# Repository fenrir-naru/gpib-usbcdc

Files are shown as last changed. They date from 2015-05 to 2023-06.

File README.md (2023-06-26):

GPIB-USBCDC
===============

_GPIB-USBCDC_ is an interface bridge between GPIB (HPIB) and USB communication device class. 
It is [Prologix GPIB-USB adapter](http://prologix.biz/gpib-usb-controller.html) clone with [EFM8 Universal Bee](https://www.silabs.com/products/mcu/8-bit/efm8-universal-bee/pages/efm8-universal-bee.aspx) or [C8051F38x](http://www.silabs.com/products/mcu/8-bit/c8051f38x/Pages/c8051f38x.aspx) microcontroller.

# Quick user guide
  1. Connect _GPIB-USBCDC_ to the PC. _GPIB-USBCDC_ is recognized as serial port, which will be installed with [CDC inf file](https://raw.githubusercontent.com/fenrir-naru/gpib-usbcdc/master/firmware/inf/gpib-usbcdc_C8051F38x.inf).
  1. Other usage is almost same as [Prologix GPIB-USB adapter](http://prologix.biz/gpib-usb-controller.html). Please see that product manual.
  
# Manual
[Nice user manual](https://github.com/fenrir-naru/gpib-usbcdc/blob/master/docs/manual_by_Alessandro.pdf) written by Alessandro Soraruf is available, Thanks!
In addition, please set up your device with its address except for zero, in case of bus confliction reported by [biergaizi](https://github.com/fenrir-naru/gpib-usbcdc/issues/5).
  
# Board
[EagleCAD](http://www.cadsoftusa.com/) files are available (ver.1 [schematics](https://github.com/fenrir-naru/gpib-usbcdc/blob/master/board/gpib-usbcdc.sch) and [layout](https://github.com/fenrir-naru/gpib-usbcdc/blob/master/board/gpib-usbcdc.brd). Its components are listed in [BOM](https://github.com/fenrir-naru/gpib-usbcdc#bom-bill-of-material). The board design is published under [Creative Commons Attribution-ShareAlike 4.0 International](http://creativecommons.org/licenses/by-sa/4.0/).

## BOM (bill of material)

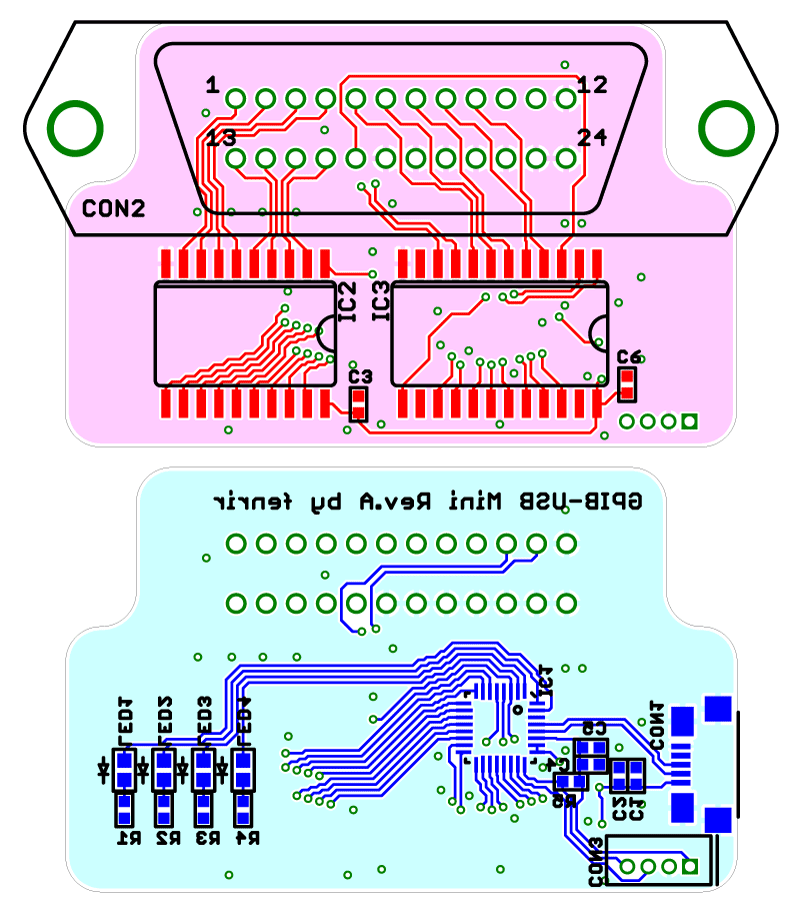
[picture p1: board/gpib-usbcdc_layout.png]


| **Part** | **Value** | **Package** | **Multiple** |
|:---|:---|:---|:---|
| C1, C4  | 1u / 6V3 | 1005 | 2 |
| C2, C3, C5, C6 | 0.1u / 10V | 1005 | 4 |
| CON1 | [HRS ZX62R-B-5P](http://www.digikey.jp/product-detail/ja/ZX62R-B-5P/H11574CT-ND/1787106) | | 1 |
| CON2 | [Norcomp 111-024-113L001](http://www.digikey.jp/product-detail/ja/0/1024PMA-ND) | | 1 |
| CON3 | [JST ZH B4B-ZR](http://www.jst-mfg.com/product/detail_e.php?series=287) | | 1 | 
| IC1 | [EFM8UB20F32G-A-QFN32](https://www.silabs.com/products/mcu/8-bit/efm8-universal-bee/pages/EFM8UB20F32G-A-QFN32.aspx) or [C8051F387-GM](http://www.silabs.com/products/mcu/8-bit/c8051f38x/pages/C8051F387-GM.aspx) | QFN32 | 1 |
| IC2 | [SN75160BDWR](http://www.ti.com/product/sn75160b) or [SN75ALS160DWR](http://www.ti.com/product/sn75als160) | SO20 | 1 |
| IC3 | [SN75162BDWR](http://www.ti.com/product/sn75162b) or [SN75ALS162DWR](http://www.ti.com/product/sn75als162) | SO24 | 1 |
| LED1 | Red | 1608 | 1 |
| LED2 | Orange | 1608 | 1 |
| LED3 | Green | 1608 | 1 |
| LED4 | Blue | 1608 | 1 |
| R1, R2, R3, R4 | 470 | 1005 | 4 |
| R5 | 1K | 1005 | 1 |

# Firmware
The official binary is published in [github release](https://github.com/fenrir-naru/gpib-usbcdc/releases). To build the firmware by yourself, install [sdcc](http://sdcc.sourceforge.net/) (testing with [ver 3.3.0 #8604](http://sourceforge.net/projects/sdcc/files/sdcc/3.3.0/)), and just "make" at "firmware" directory of the downloaded [code](https://github.com/fenrir-naru/gpib-usbcdc/tree/master/firmware). The generated firmware name is  `gpib-usbcdc.hex`. The firmware code is published under [New BSD License](http://opensource.org/licenses/BSD-3-Clause). 



## How to write firmware to hardware
Connect a _GPIB-USBCDC_ board and a PC via [USB debug adapter (UDA)](http://www.silabs.com/products/mcu/pages/usbdebug.aspx) or compatible one. The minimum required programming connections are summarized in the following table. Then, use [Flash Programming Utilities](http://www.silabs.com/products/mcu/Pages/8-bit-microcontroller-software.aspx#flash). Note: the board may not be recognized by a PC when an UDA is connected via USB hubs. UDA is recommended to connect a PC directly.

| **Signal** | **UDA side** | **_GPIB-USBCDC_ board side** |
|:---|:---|:---|
| C2D | 4th pin | CON3 3rd pin |
| C2CK | 7th pin | CON3 4th pin |
| GND | 3rd pin | CON3 1st pin |

# Additional information
* The project owner's website is [Fenrir's BLog](http://fenrir.naruoka.org/).

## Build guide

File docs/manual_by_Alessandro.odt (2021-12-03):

fenrir / hugen79

GPIB-USBCDC CONTROLLER

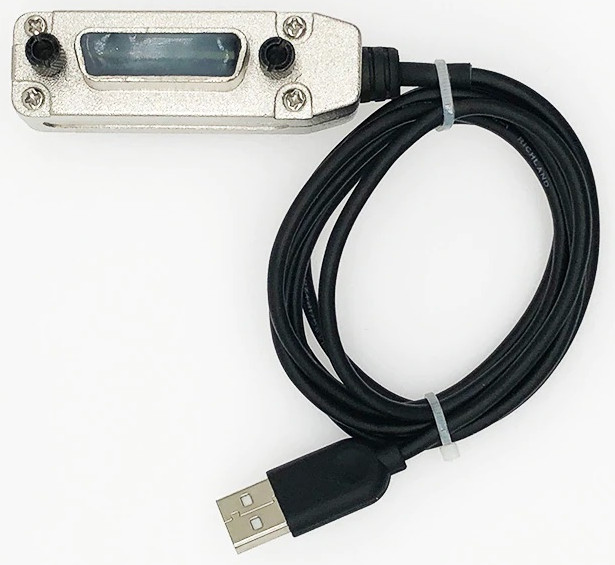
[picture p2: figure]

USER MANUAL

Version 1.2

Dec 02, 2021

Change Log

Nov 27, 2021 | Initial version
Nov 29, 2021 | Added “debug 0” description
Dec 02, 2021 | Added Hugen79 pics and FW update connector pin description

# Introduction

Fenrir GPIB-USBCDC is an interface bridge between GPIB (HPIB) and USB communication device class. It is a Prologix GPIB-USB adapter clone with EFM8 Universal Bee or C8051F38x microcontroller.

Fenrir GPIB-USBCDC controller converts any computer with a USB port into a GPIB Controller or Device.

In Controller mode, Fenrir GPIB-USBCDC controller can remotely control GPIB enabled instruments such as Oscilloscopes, Logic Analyzers, and Spectrum Analyzers.

In Device mode, Fenrir GPIB-USBCDC controller converts the computer into a GPIB peripheral for downloading data and screen plots from the instrument front panel.

In both modes, Fenrir GPIB-USBCDC controller interprets high level commands received from the host computer and performs the appropriate low-level GPIB protocol handshaking.

# Installation

Fenrir GPIB-USBCDC controller is recognized as serial port, which will be installed with CDC .inf file. To install it, simply connect the Fenrir GPIB-USBCDC to the PC and it will be automatically discovered and installed by the operating system.

# Firmware

The official firmware binary is published in github release (https://github.com/fenrir-naru/gpib-usbcdc/releases). To build the firmware by yourself, install Small Device C Compiler - S (http://sdcc.sourceforge.net/)DCC (testing with ver 3.3.0 #8604 (http://sourceforge.net/projects/sdcc/files/sdcc/3.3.0/)), and just "make" at "firmware" directory of the downloaded code. The generated firmware name is gpib-usbcdc.hex. The firmware code is published under New BSD License (http://opensource.org/licenses/BSD-3-Clause).

Depending on the hardware you are using you will need the original fenrir firmware or hugen79 modded firmware.

Fenrir git URL: https://github.com/fenrir-naru/gpib-usbcdc

Hugen79 git URL: https://github.com/hugen79/gpib-usbcdc

## Write firmware to hardware

Connect a GPIB-USBCDC board and a PC via USB debug adapter (UDA) (http://www.silabs.com/products/mcu/pages/usbdebug.aspx) or compatible one. The minimum required programming connections are summarized in the following table. Then, use Flash Programming Utilities (http://www.silabs.com/products/mcu/Pages/8-bit-microcontroller-software.aspx#flash).

Note:

the board may not be recognized by a PC when an UDA is connected via USB hubs. UDA is recommended to connect a PC directly.

Signal | UDA side | Fenrir GPIB-USBCDC board side | Hugen79 GPIB-USBCDC board side
C2D | 4th pin | CON3 3rd pin | V.D.C.G. 2nd pin
C2CK | 7th pin | CON3 4th pin | V.D.C.G. 3rd pin
GND | 3rd pin | CON3 1st pin | V.D.C.G. 4th pin

See Fenrir layout and Hugen79 PCB for more detail on connectors.

# Host Software

A wide variety of host software may be used to communicate with Fenrir GPIB-USBCDC controller:

Terminal programs – any terminal emulation program such as HyperTerminal, Tera Term Pro, or Minicom can be used to communicate with the controller and instruments connected to it.

Custom applications – any programming language or environment that provides access to serial ports (if using VCP driver) or allows interfacing to DLL (if using D2XX driver) may be used to develop custom applications. Graphical programming environments like National Instruments LabView and Agilent VEE may be used as well.

EZGPIB – an easy to use, programming environment developed by Ulrich Bangert for developing data acquisition applications. Web link to this tool can be found at prologix.biz.

Plotter emulators – plotter emulation applications such as 7470.exe, PrintCapture and Plottergeist can be used to render screen plots downloaded using Fenrir GPIB-USBCDC controller. Details on how to configure these tools are available at prologix.biz.

# Configuration

Fenrir GPIB-USBCDC controller can be configured using any of the following methods:

Prologix.exe – Prologix.exe is an open source tool developed by John Miles for configuring the controller. Web link to the tool can be found at prologix.biz.

Terminal program – any terminal emulation program such as HyperTerminal, Tera Term Pro, or Minicom can be used to configure the controller by manually entering appropriate commands (See Commands). Using the terminal program open the virtual COM port created by the USB driver. Serial port parameters such as baud rate, data bits, stop bits and flow control do not matter and may be set to any value. You may want to enable the “Local Echo” feature in the terminal program to view the commands being entered. Please consult the FAQ at prologix.biz, or the program’s user manual, for detailed configuration steps for various terminal programs.

Fenrir GPIB-USBCDC Controller stores the latest configuration settings in non-volatile memory. These settings are not address specific. If you have multiple instruments on the GPIB bus that require different configuration settings, you must change the settings before communicating with each instrument.

# Operating Modes

Fenrir GPIB-USBCDC controller can operate in two modes – CONTROLLER and DEVICE. You can switch between the two modes using ++mode command (see Commands).

## Controller Mode

In Controller mode, the GPIB-USB Controller acts as the Controller-In-Charge (CIC) on the GPIB bus. When the controller receives a command over the USB port terminated by the USB terminator – CR (ASCII 13) or LF (ASCII 10) – it addresses the GPIB instrument at the currently specified address (See ++addr command) to listen, and passes along the received data.

When Read-After-Write feature is enabled (See ++auto command) Fenrir GPIB-USBCDC Controller will addresses the instrument to talk after sending a command, in order to read its response. All data received from instruments over GPIB is sent to host over USB. Read-After-Write feature simplifies communication with instruments. You send commands and read responses without consideration for low level GPIB protocol details.

When Read-After-Write feature is not enabled Fenrir GPIB-USBCDC controller does not automatically address the instrument to talk. You must use the ++read command to read data.

Controller mode is used to remotely control instruments and to download screen plots by sending plot commands from a host computer.

## Device Mode

In Device mode, Fenrir GPIB-USBCDC Controller acts as another peripheral on the GPIB bus. In this mode, the controller can act as a GPIB TALKER or GPIB LISTENER only. Since Fenrir GPIB-USBCDC Controller is not the Controller-In-Charge while in this mode, it expects to receive commands from a GPIB controller. When Device mode is enabled Fenrir GPIB-USBCDC controller configures itself as a GPIB Listener.

All data received by the controller over the GPIB port is passed along to the USB port without buffering. All data received from the host over USB is buffered until the GPIB controller addresses Fenrir GPIB-USBCDC controller to talk, at which time the buffered data is passed along to the GPIB port. The controller can buffer only one command. A subsequent command received over USB will overwrite the previously buffered one, if the previous one has not yet been transmitted over GPIB.

Device mode is used to download screen plots from the instrument front panel for rendering using plotter emulation software.

# Data Transmission

In Controller and Device modes, characters received over USB port are aggregated in an internal buffer and interpreted when a USB termination character – CR (ASCII 13) or LF (ASCII 10) – is received. If CR, LF, ESC (ASCII 27), or ‘+’ (ASCII 43) characters are part of USB data they must be escaped by preceding them with an ESC character. All un-escaped LF, CR and ESC and ‘+’ characters in USB data are discarded.

As mentioned earlier, an un-escaped CR or LF acts as the USB terminator. The terminating CR or LF is removed and GPIB termination characters (specified by ++eos command) are appended before transmitting data to instruments.

Any USB input that starts with the unescaped “++” character sequence is interpreted as a controller command and not transmitted over GPIB.

When configured to do so – using the ++auto command or the ++read command – characters received from instruments are transmitted to host. Unlike while sending data to instruments, no character substitution is performed. The firmware buffers only one character. The USB driver may provide additional buffering. If a device is talking and the buffers (firmware’s and driver’s) are full, the device continues to be in TALK mode but is stopped from further sending data using GPIB handshaking.

The ++eot_char command may be used to detect GPIB EOI signal assertion.

## Binary Data Transmission

Fenrir GPIB-USBCDC controller can send and receive binary data to and from GPIB enabled instruments.

No special action is necessary to receive binary data from instruments. Any binary data received from the instrument is transmitted over USB to PC unmodified, just as with ASCII data. Since binary data from instruments is not usually terminated by CR or LF characters (as is usually the case with ASCII data), you may want to use the ++eot_enable command to detect EOI indicating end of data. See ++eot_enable command help for more details.

Special care must be taken when sending binary data to instruments. If any of the following characters occur in the binary data -- CR (ASCII 13), LF (ASCII 10), ESC (ASCII 27), ‘+’ (ASCII 43) – they must be escaped by preceding them with an ESC character.

For example, to send the following (decimal) binary data:

00 01 02 13 03 10 04 27 05 43 06

it must be escaped as follows:

00 01 02 27 13 03 27 10 04 27 27 05 27 43 06

Further more, most instruments will get confused if GPIB termination characters, such as CR or LF, are appended to binary data. Use ++eos 3 command to disable such behavior. See ++eos command help for more details.

# Commands Prologix compatible

Fenrir GPIB-USBCDC controller provides several commands to configure its behavior. They are explained in detail in the following sections. All commands start with the “++” character sequence.

Commands must be terminated with CR or LF.

## addr

The addr command is used to configure, or query the GPIB address. Meaning of the GPIB address depends on the operating mode of the controller. In CONTROLLER mode, it refers to the GPIB address of the instrument being controlled. In DEVICE mode, it is the address of the GPIB peripheral that Fenrir GPIB-USBCDC controller is emulating.

An optional secondary address may also be specified. Secondary address must be separated from the primary address by a space character. Valid secondary address values are 96 to 126 (decimal). Secondary address value of 96 corresponds to secondary GPIB address of 0, 97 corresponds to 1, and so on. Specifying secondary address has no effect in DEVICE mode.

If the command is issued with no parameters, the currently configured address (primary, and secondary, if specified) is returned.

SYNTAX: ++addr [<PAD>[<SAD>]]

where:

PAD (Primary Address) is a decimal value between 0 and 30.

SAD (Secondary Address) is a decimal value between 96 and 126. SAD is optional.

MODES AVAILABLE: CONTROLLER, DEVICE

EXAMPLES:

++addr 5 – Set primary address to 5

++addr – Query current address

++addr 9 96 – Set primary address to 9 and secondary address to 0

NOTE:

Default GPIB address of many HP-GL/2 plotters is 5.

## auto

Fenrir GPIB-USBCDC controller can be configured to automatically address instruments to talk after sending them a command in order to read their response. The feature called, Read-After-Write, saves the user from having to issue read commands repeatedly. This command enabled or disabled the Read-After-Write feature.

In addition, auto command also addresses the instrument at the currently specified address to TALK or LISTEN. ++auto 0 addresses the instrument to LISTEN and ++auto 1 addresses the instrument to TALK.

If the command is issued without any arguments it returns the current state of the readafter-write feature.

SYNTAX: ++auto [0|1]

MODES AVAILABLE: CONTROLLER

NOTE:

Some instruments generate “Query Unterminated” or “-420” error if they are addressed to talk after sending a command that does not generate a response (often called nonquery commands). In effect the instrument is saying, I have been asked to talk but I have nothing to say. The error is often benign and may be ignored. Otherwise, use the ++read command to read the instrument response. For example:

++auto 0 — Turn off read-after-write and address instrument to listen

SET VOLT 1.0 — Non-query command

*IDN? — Query command

++read eoi — Read until EOI asserted by instrument

"HP54201A" — Response from instrument

## clr

This command sends the Selected Device Clear (SDC) message to the currently specified GPIB address. Please consult the programming manual for details on how a particular instrument responds to this message.

SYNTAX: ++clr

MODES AVAILABLE: CONTROLLER

## eoi

This command enables or disables the assertion of the EOI signal with the last character of any command sent over GPIB port. Some instruments require EOI signal to be asserted in order to properly detect the end of a command.

SYNTAX: ++eoi [0|1]

MODES AVAILABLE: CONTROLLER, DEVICE

EXAMPLES:

++eoi 1 - Enable EOI assertion with last character

++eoi 0 - Disable EOI assertion

++eoi - Query if EOI assertion is enabled or disabled

## eos

This command specifies GPIB termination characters. When data from host is received over USB, all non-escaped LF, CR and ESC characters are removed and GPIB terminators, as specified by this command, are appended before sending the data to instruments. This command does not affect data from instruments received over GPIB port.

If the command is issued with no arguments then the current configuration is returned.

SYNTAX: ++eos [0|1|2|3]

where:

0 – CR+LF,

1 – CR,

2 – LF,

3 – None

MODES AVAILABLE: CONTROLLER, DEVICE

EXAMPLES:

++eos 0 - Append CR+LF to instrument commands

++eos 1 - Append CR to instrument commands

++eos 2 - Append LF to instrument commands

++eos 3 - Do not append anything to instrument commands

++eos - Query current EOS state

## eot_enable

This command enables or disables the appending of a user specified character (see also ++eot_char) to USB output whenever EOI is detected while reading a character from the GPIB port.

If the command is issued without any argument, the current state of eot_enable is returned.

SYNTAX: ++eot_enable [0|1]

MODES AVAILABLE: CONTROLLER, DEVICE

EXAMPLES:

++eot_enable 1 - Append user defined character when EOI detected

++eot_enable 0 - Do not append character when EOI detected

++eot_enable - Query current eot_enable state

## eot_char

This command specifies the character to be appended to USB output when eot_enable is set to 1 and EOI is detected.

If the command is issued without any argument, the currently specified character is returned.

SYNTAX: ++eot_char [<char>]

where:

<char> is a decimal value less than 256

MODES AVAILABLE: CONTROLLER, DEVICE

EXAMPLES:

++eot_char 42 - Append * (ASCII 42) when EOI is detected

++eot_char - Query currently configured eot_char

## ifc

This command asserts GPIB IFC signal for 150 microseconds making Prologix GPIBUSB controller the Controller-In-Charge on the GPIB bus.

SYNTAX: ++ifc

MODES AVAILABLE: CONTROLER

## llo

This command disables front panel operation of the currently addressed instrument.

SYNTAX: ++llo

MODES AVAILABLE: CONTROLLER

## loc

This command enables front panel operation of the currently addressed instrument.

SYNTAX: ++loc

MODES AVAILABLE: CONTROLLER

## lon

This command configures the GPIB-USB controller to listen to all traffic on the GPIB bus, irrespective of the currently specified address. This configuration is also known as “listen-only” mode. In this mode, the controller can only receive, but cannot send any data.

SYNTAX: ++lon [0|1]

MODES AVAILABLE: DEVICE

EXAMPLES:

++lon 1 - Enable “listen-only” mode

++lon 0 - Disable “listen-only” mode

++lon - Query “listen-only” mode

## mode

This command configures the Fenrir GPIB-USBCDC controller to be a CONTROLLER or DEVICE.

If the command is issued without any arguments, the current mode is returned.

SYNTAX: ++mode [0|1]

where:

1 – CONTROLLER,

0 – DEVICE

MODES AVAILABLE: CONTROLLER, DEVICE

EXAMPLES:

++mode 1 - Switch to CONTROLLER mode

++mode 0 - Switch to DEVICE mode

++mode - Query current mode

## read_tmo_ms

This command specifies the timeout value, in milliseconds, to be used in the ++read command and ++spoll command. Timeout may be set to any value between 1 and 3000 milliseconds.

SYNTAX: ++read_tmo_ms <time>

where:

<time> is decimal value between 1 and 3000

MODES AVAILABLE: CONTROLLER

## rst

This command performs a power-on reset of the controller. The process takes about 5 seconds. All input received over USB during this time are ignored.

SYNTAX: ++rst

MODES AVAILABLE: CONTROLLER, DEVICE

## spoll

This command performs a serial poll of the instrument at the specified address. If no address is specified then this command serial polls the currently addressed instrument (as set by a previous ++addr command). This command uses the time-out value specified by the ++read_tmo_ms command.

SYNTAX: ++spoll [<PAD>[<SAD>]]

where:

PAD (Primary Address) is a decimal value between 0 and 30.

SAD (Secondary Address) is a decimal value between 96 and 126. SAD is optional.

MODES AVAILABLE: CONTROLLER

EXAMPLE:

++spoll 5 - Serial poll instrument at primary address 5

++spoll 9 96 - Serial poll instrument at primary address 9, secondary address 0

++spoll - Serial poll currently addressed instrument

## srq

This command returns the current state of the GPIB SRQ signal. The command returns ‘1’ is SRQ signal is asserted (low) and ‘0’ if the signal is not asserted (high).

SYNTAX: ++srq

MODES AVAILABLE: CONTROLLER

## status

The ++status command is used to specify the device status byte to be returned when serial polled by a GPIB controller. If the RQS bit (bit #6) of the status byte is set then the SRQ signal is asserted (low). After a serial poll,

SRQ line is de-asserted and status byte is set to 0. Status byte is initialized to 0 on power up. SRQ is also de-asserted and status byte is cleared if DEVICE CLEAR (DCL) message, or SELECTED DEVICE CLEAR (SDC) message, is received from the GPIB controller.

If the command is issued without any arguments it returns the currently specified status byte.

SYNTAX: ++status [0-255]

MODES AVAILABLE: DEVICE

EXAMPLE:

++status 48 - Specify serial poll status byte as 48. Since bit #6 is set, this command will assert SRQ.

++status - Query current serial poll status byte.

## trg

This command issues Group Execute Trigger GPIB command to devices at the specified addresses. Up to 15 addresses maybe specified. Addresses must be separated by spaces. If no address is specified then Group Execute Trigger command is issued to the currently addressed instrument (as set by a previous ++addr command). Refer to the programming manual for a specific instrument’s response to Group Execute Trigger command.

SYNTAX: ++trg [<PAD1> [<SAD1>] <PAD2> [SAD2] … <PAD15> [<SAD15>]]

MODES AVAILABLE: CONTROLLER

## ver

This command returns the version string of the Fenrir GPIB-USBCDC controller.

SYNTAX: ++ver

MODES AVAILABLE: CONTROLLER, DEVICE

## help

This command prints a brief summary of all available commands.

SYNTAX: ++help

MODES AVAILABLE: CONTROLLER, DEVICE

# Commands different from Prologix

There is a small set of commands with a little different implementation from Prologix one or some new commands not available in Prologix USB Controller.

## read

This command can be used to read data from an instrument until:

- EOI is detected or timeout expires, or
- Timeout expires

Timeout is set using the ++read_tmo_ms command and applies to inter-character delay, i.e., the delay since the last character was read. Timeout is not be confused with the total time for which data is read.

SYNTAX: ++read [eoi]

MODES AVAILABLE: CONTROLLER

EXAMPLES:

++read - Read until timeout

++read eoi - Read until EOI detected or timeout

## savecfg

This command saves the current values of all configuration parameters in the internal EPROM.

SYNTAX: ++savecfg

MODES AVAILABLE: CONTROLLER, DEVICE

## debug

This command enables the debug output for each command issued.

If the command is issued without any arguments it returns the currently debug level.

SYNTAX: ++debug [<level>]

where:

<level> is a bitmask in decimal format of:

0 (000000000) disable debug

1 (000000001) enable serial command echo

2 (000000010) enable GPIB echo

4 (000000100) verbose output

MODES AVAILABLE: CONTROLLER, DEVICE

EXAMPLE:

++debug 0 - Disables debug

++debug 1 - Enables echo of serial commands issued

++debug 2 - Enables GPIB echo

++debug 3 - Enables echo of serial commands and GPIB

++debug 4 - Enables verbose output

++debug 5 - Enables verbose output and echo of serial commands

++debug 6 - Enables verbose output and GPIB echo

++debug 7 - Enables verbose output and echo of serial commands and GPIB

++debug - Query current debug level

# Specifications and Technical details

Supported OS: Microsoft Windows (7 or later), Mac OS X, Linux (kernel 2.6 or later), FreeBSD

Supported Standards: IEEE 488.1, IEEE 488.2, USB 1.1, USB 2.0

GPIB commands not supported: PARALLEL POLL, PASS CONTROL

Power: USB bus powered, +5V, 100 mA (max)

Supported USB hubs: Self-powered and Bus-powered hubs

Indicators: TALK, LISTEN, CONTOLLER MODE, ACTIVITY

## Fenrir layout


## Hugen79 schematics

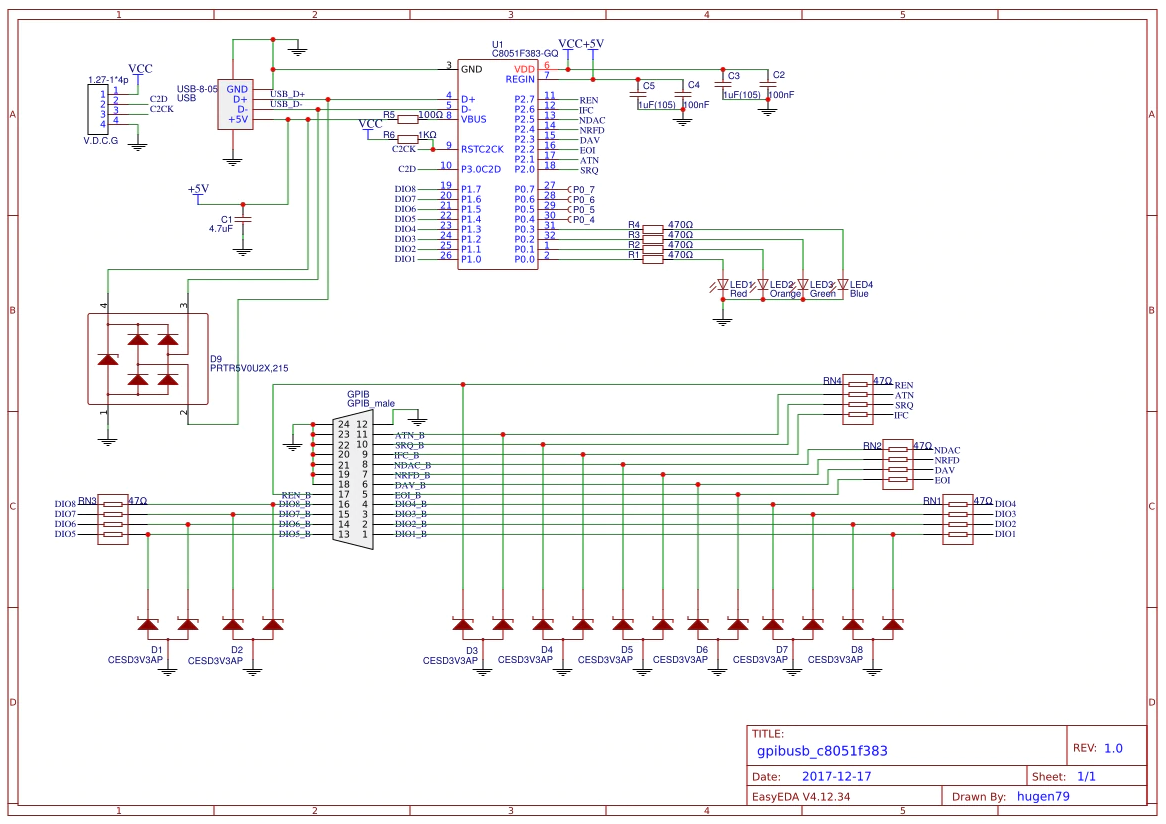
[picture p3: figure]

## Hugen79 PCB

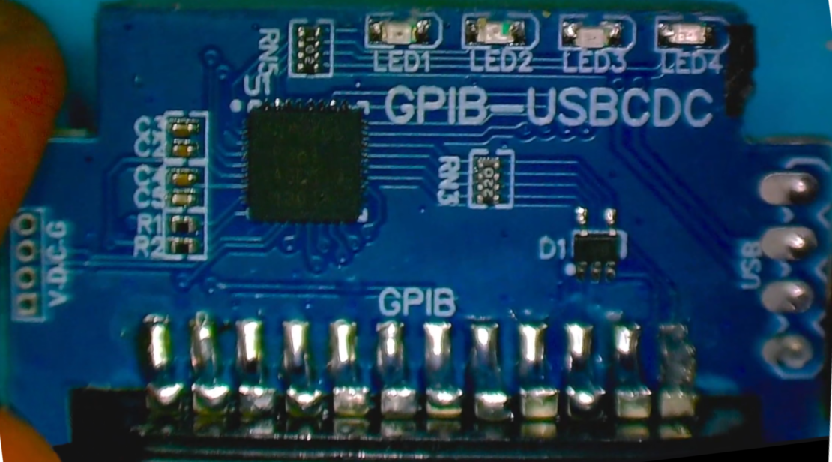
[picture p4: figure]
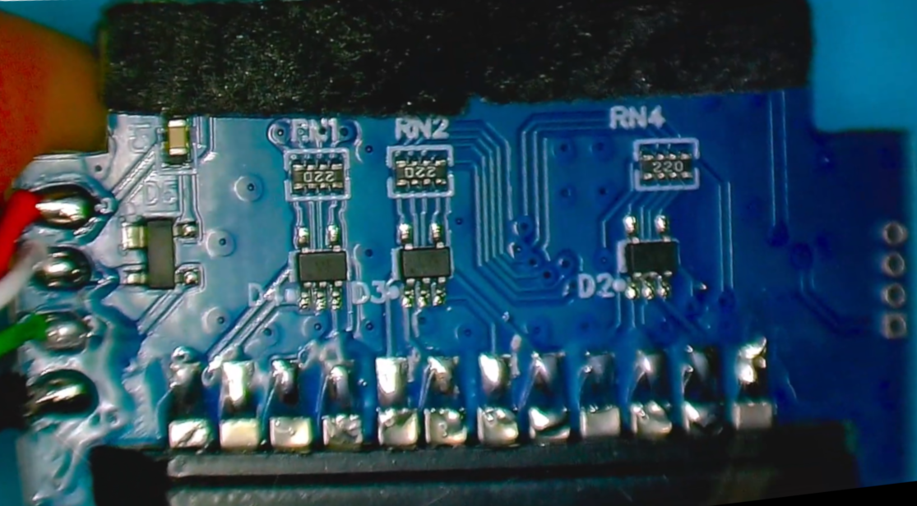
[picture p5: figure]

GPIB-USBCDC User Manual

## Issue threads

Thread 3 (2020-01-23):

Popping up as GPIB-USB comport

Decee1, 2020-01-23:
Hello.

Is this device supposed to pop up as a GPIB-USB comport?
if so, i'd guess it doesn't support Pyvisa with multiple instruments or does it?

fenrir-naru, 2020-01-24:
Hi, thank you for your comment.
I do not know PyVISA well at this time. The function of GPIB-USBCDC is just a bridge between USB COM port and GPIB, which may mean you can control it from PyVISA if you can write a driver to wrap its commands for PyVISA.

Decee1, 2020-06-18:
If anyone else was confused about this i made a Library today that can use the prologix. It is as simple as the Pyvisa driver
https://github.com/Decee1/GPIBprologix

Closed 2020-01-24.

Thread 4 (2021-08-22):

Correct firmware for C8051F387

feroxib, 2021-08-22:
Hello,
I wanted to ask if there is a firmware version for the adapter if you're using a C8051F387
You recommended either the  EFM8UB20F32G-A-QFN32 or C8051F387.
But im having problems with Windows detecting the adapter correctly.
Do i have to build my own firmware or is there a premade one?

Thank you for your help

fenrir-naru, 2021-08-24:
@feroxib Thank you for your comment.
I think there is no significant difference between the two devices, but I am not sure.
I will attach [C8051F38x datasheet](https://github.com/fenrir-naru/gpib-usbcdc/files/7035788/C8051F38x.pdf) I locally downloaded, please check it.

Closed 2021-08-24.

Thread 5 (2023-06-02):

Documentation: Add Warning about GPIB Address 0

biergaizi, 2023-06-02:
I spent days trying to get this GPIB converter to work on my voltmeter but I couldn't even after checking the documentation many times. The voltmeter did not not respond to any command. Meanwhile, strangely, a National Instruments converter (clone) worked without any problem. Eventually I had to troubleshoot this problem by probing the GPIB bus painstalkingly with a logic analyzer. The conclusion was almost hilarious: the voltmeter's GPIB address was set to 0, which is ambiguous, and I didn't realize it.

After I changed the address, it worked flawlessly.

This is not a bug since address 0 is reserved. But I suggest updating the documentation with a warning on GPIB device address 0, so other newcomers don't have to fall into the same trap.

## Debugging

If the controller set the device as a listener first and set itself as a talker, it creates a bus contention - both the controller and the device have address 0 and both think they should start talking now, trashing the bus, so it doesn't work. This is the behavior of gpib-usbcdc.

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

But... If the controller set itself as a talker first before set the device as a listener, it works (in a mysterious way if you don't have a logic analyzer), because there's only one active talker at this point. Apparently National Instruments does this, perhaps as a workaround just for this case. So it worked without any problem.

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

fenrir-naru, 2023-06-26:
@biergaizi Thank you so much. I added some text to Readme based on your report.

Closed 2023-06-26.

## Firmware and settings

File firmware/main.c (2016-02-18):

/*
 * Copyright (c) 2015, M.Naruoka (fenrir)
 * All rights reserved.
 *
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
 * THIS SOFTWARE IS PROVIDED BY THE COPYRIGHT HOLDERS AND CONTRIBUTORS "AS IS"
 * AND ANY EXPRESS OR IMPLIED WARRANTIES, INCLUDING, BUT NOT LIMITED TO,
 * THE IMPLIED WARRANTIES OF MERCHANTABILITY AND FITNESS FOR A PARTICULAR PURPOSE
 * ARE DISCLAIMED. IN NO EVENT SHALL THE COPYRIGHT HOLDER OR CONTRIBUTORS
 * BE LIABLE FOR ANY DIRECT, INDIRECT, INCIDENTAL, SPECIAL, EXEMPLARY,
 * OR CONSEQUENTIAL DAMAGES (INCLUDING, BUT NOT LIMITED TO,
 * PROCUREMENT OF SUBSTITUTE GOODS OR SERVICES;
 * LOSS OF USE, DATA, OR PROFITS; OR BUSINESS INTERRUPTION)
 * HOWEVER CAUSED AND ON ANY THEORY OF LIABILITY, WHETHER IN CONTRACT,
 * STRICT LIABILITY, OR TORT (INCLUDING NEGLIGENCE OR OTHERWISE)
 * ARISING IN ANY WAY OUT OF THE USE OF THIS SOFTWARE,
 * EVEN IF ADVISED OF THE POSSIBILITY OF SUCH DAMAGE.
 *
 */

#include <stdio.h>
#include <stdlib.h>

#include "main.h"
#include "util.h"

#include "c8051f380.h"
#include "f38x_usb.h"
#include "gpib.h"

volatile __xdata u32 global_ms = 0;
volatile __xdata u32 tickcount = 0;
volatile __xdata u8 sys_state = 0;
volatile u8 timeout_10ms = 0;

void sysclk_init();
void port_init();
void timer_init();

#ifdef USE_ASM_FOR_SFR_MANIP
#define led_on(i)     {__asm orl _P0,SHARP  (0x01 << (i - 1)) __endasm; }
#define led_off(i)    {__asm anl _P0,SHARP ~(0x01 << (i - 1)) __endasm; }
#define led_toggle(i) {__asm xrl _P0,SHARP  (0x01 << (i - 1)) __endasm; }
#else
#define led_on(i)     (P0 |=  (0x01 << (i - 1)))
#define led_off(i)    (P0 &= ~(0x01 << (i - 1)))
#define led_toggle(i) (P0 ^=  (0x01 << (i - 1)))
#endif

void main() {
  sysclk_init(); // Initialize oscillator
  wait_ms(1000);
  port_init(); // Initialize crossbar and GPIO

  gpib_init();

  timer_init();
  
  EA = 1; // Global Interrupt enable

  usb0_init();

  while (1) {
    gpib_polling();
    usb_polling();

    if(sys_state & SYS_PERIODIC_ACTIVE){
      sys_state &= ~SYS_PERIODIC_ACTIVE;
      led_toggle(1);
    }

    if(sys_state & SYS_GPIB_CONTROLLER){
      led_on(2);
    }else{
      led_off(2);
    }

    { // check talked
      static __xdata u8 persistent = 0;
      if(sys_state & SYS_GPIB_TALKED){
        led_on(3);
        persistent = 0x40;
      }else if(persistent > 0){
        led_toggle(3);
        persistent--;
      }else{
        led_off(3);
      }
    }

    { // check listened
      static __xdata u8 persistent = 0;
      if(sys_state & SYS_GPIB_LISTENED){
        led_on(4);
        persistent = 0x40;
      }else if(persistent > 0){
        led_toggle(4);
        persistent--;
      }else{
        led_off(4);
      }
    }
  }
}

// System clock selections (SFR CLKSEL)
#define SYS_INT_OSC              0x00        // Select to use internal oscillator
#define SYS_4X_MUL               0x03        // Select to use internal oscillator
#define SYS_EXT_OSC              0x01        // Select to use an external oscillator
#define SYS_4X_DIV_2             0x02

// USB clock selections (SFR CLKSEL)
#define USB_4X_CLOCK             0x00        // Select 4x clock multiplier, for USB Full Speed
#define USB_INT_OSC_DIV_2        0x10        // See Data Sheet section 13. Oscillators
#define USB_EXT_OSC              0x20
#define USB_EXT_OSC_DIV_2        0x30
#define USB_EXT_OSC_DIV_3        0x40
#define USB_EXT_OSC_DIV_4        0x50

void sysclk_init(){
  REF0CN = 0x07;
  
  // Configure internal oscillator for its maximum frequency and enable missing clock detector
  OSCICN |= 0x03;

#ifdef _USB_LOW_SPEED_
  CLKSEL  = SYS_INT_OSC; // Select System clock
  CLKSEL |= USB_INT_OSC_DIV_2; // Select USB clock
#else
  // Select internal oscillator as input to clock multiplier
  CLKMUL  = 0x00;
  CLKMUL |= 0x80; // Enable clock multiplier
  wait_ms(1); // Delay for clock multiplier to begin
  CLKMUL |= 0xC0; // Initialize the clock multiplier
  wait_ms(1);
  while(!(CLKMUL & 0x20)); // Wait for multiplier to lock
  CLKSEL = SYS_4X_MUL;
  CLKSEL |= USB_4X_CLOCK; // Select USB clock
#endif  /* _USB_LOW_SPEED_ */
}


void port_init() {
  
  // Default port state
  // Pn = 1 (High), PnMDIN = 1 (not analog), PnMDOUT = 0 (open-drain) => Hi-Z
  
  // P0
  // 0-7 => GPIO
  P0MDIN = 0xFF;
  P0MDOUT = 0x0F; // 0-3 => push-pull, 4-7 => open-drain
  P0 = 0xF0;
  P0SKIP = 0xFF;
  
  // P1 => GPIO
  P1MDIN = 0xFF;
  P1MDOUT = 0x00; // open-drain
  P1 = 0xFF;
  P1SKIP = 0xFF;
  
  // P2 = GPIO
  P2MDIN = 0xFF; 
  P2MDOUT = 0x00; // open-drain
  P2 = 0xFF;
  P2SKIP = 0xFF;
  
  // P3
  P3MDIN = 0xFF;
  P3MDOUT = 0xFF;
  P3 = 0x00;

  XBR0 = 0x00;
  XBR2 = 0x00;
  XBR1 = 0x40;  // Enable crossbar
}

void timer_init(){
  TMR3CN = 0x00;    // Stop Timer3; Clear TF3;
  CKCON &= ~0xC0;   // Timer3 clocked based on T3XCLK;
  TMR3RL = (0x10000 - (SYSCLK/12/100));  // Re-initialize reload value (100Hz, 10ms)
  TMR3 = 0xFFFF;    // Set to reload immediately
  EIE1 |= 0x80;     // Enable Timer3 interrupts(ET3)
  TMR3CN |= 0x04;   // Start Timer3(TR3)
}

/**
 * interrupt routine invoked when timer3 overflow
 * 
 */
void interrupt_timer3() __interrupt (INTERRUPT_TIMER3) {
  TMR3CN &= ~0x80; // Clear interrupt
  global_ms += 10;
  tickcount++;
  timeout_10ms++;
  sys_state |= SYS_PERIODIC_ACTIVE;
}

unsigned char _sdcc_external_startup(){
  PCA0MD &= ~0x40; ///< Disable Watchdog timer
  return 0;
}

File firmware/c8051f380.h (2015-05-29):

/*
 * Copyright (c) 2015, M.Naruoka (fenrir)
 * All rights reserved.
 *
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
 * THIS SOFTWARE IS PROVIDED BY THE COPYRIGHT HOLDERS AND CONTRIBUTORS "AS IS"
 * AND ANY EXPRESS OR IMPLIED WARRANTIES, INCLUDING, BUT NOT LIMITED TO,
 * THE IMPLIED WARRANTIES OF MERCHANTABILITY AND FITNESS FOR A PARTICULAR PURPOSE
 * ARE DISCLAIMED. IN NO EVENT SHALL THE COPYRIGHT HOLDER OR CONTRIBUTORS
 * BE LIABLE FOR ANY DIRECT, INDIRECT, INCIDENTAL, SPECIAL, EXEMPLARY,
 * OR CONSEQUENTIAL DAMAGES (INCLUDING, BUT NOT LIMITED TO,
 * PROCUREMENT OF SUBSTITUTE GOODS OR SERVICES;
 * LOSS OF USE, DATA, OR PROFITS; OR BUSINESS INTERRUPTION)
 * HOWEVER CAUSED AND ON ANY THEORY OF LIABILITY, WHETHER IN CONTRACT,
 * STRICT LIABILITY, OR TORT (INCLUDING NEGLIGENCE OR OTHERWISE)
 * ARISING IN ANY WAY OUT OF THE USE OF THIS SOFTWARE,
 * EVEN IF ADVISED OF THE POSSIBILITY OF SUCH DAMAGE.
 *
 */

/*-----------------------------------------------------------------------------
C8051F380.H

Header file for Silabs C8051F380/1/2/3/4/5/6 and C8051F387 devices.
-----------------------------------------------------------------------------*/


#ifndef __C8051F380_H__
#define __C8051F380_H__

/* SFRPage 0x00 and SFRPage 0x0F Registers */
__sfr __at (0x80) P0            ; /* Port 0 Latch                             */
__sfr __at (0x81) SP            ; /* Stack Pointer                            */
__sfr __at (0x82) DPL           ; /* Data Pointer Low                         */
__sfr __at (0x83) DPH           ; /* Data Pointer High                        */
__sfr __at (0x84) EMI0TC        ; /* External Memory Interface Timing         */
__sfr __at (0x85) EMI0CF        ; /* External Memory Interface Configuration  */
__sfr __at (0x86) OSCLCN        ; /* Internal Low-Frequency Oscillator Control */
__sfr __at (0x87) PCON          ; /* Power Control                            */
__sfr __at (0x88) TCON          ; /* Timer/Counter Control                    */
__sfr __at (0x89) TMOD          ; /* Timer/Counter Mode                       */
__sfr __at (0x8A) TL0           ; /* Timer/Counter 0 Low                      */
__sfr __at (0x8B) TL1           ; /* Timer/Counter 1 Low                      */
__sfr __at (0x8C) TH0           ; /* Timer/Counter 0 High                     */
__sfr __at (0x8D) TH1           ; /* Timer/Counter 1 High                     */
__sfr __at (0x8E) CKCON         ; /* Clock Control                            */
__sfr __at (0x8F) PSCTL         ; /* Program Store R/W Control                */
__sfr __at (0x90) P1            ; /* Port 1 Latch                             */
__sfr __at (0x91) TMR3CN        ; /* Timer/Counter 3 Control         (page 0) */
__sfr __at (0x92) TMR3RLL       ; /* Timer/Counter 3 Reload Low      (page 0) */
__sfr __at (0x93) TMR3RLH       ; /* Timer/Counter 3 Reload High     (page 0) */
__sfr __at (0x94) TMR3L         ; /* Timer/Counter 3 Low                      */
__sfr __at (0x95) TMR3H         ; /* Timer/Counter 3 High                     */
__sfr __at (0x96) USB0ADR       ; /* USB0 Indirect Address Register           */
__sfr __at (0x97) USB0DAT       ; /* USB0 Data Register                       */
__sfr __at (0x91) TMR4CN        ; /* Timer/Counter 4 Control         (page F) */
__sfr __at (0x92) TMR4RLL       ; /* Timer/Counter 4 Reload Low      (page F) */
__sfr __at (0x93) TMR4RLH       ; /* Timer/Counter 4 Reload High     (page F) */
__sfr __at (0x98) SCON0         ; /* UART0 Control                            */
__sfr __at (0x99) SBUF0         ; /* UART0 Data Buffer                        */
__sfr __at (0x9A) CPT1CN        ; /* Comparator 1 Control                     */
__sfr __at (0x9B) CPT0CN        ; /* Comparator 0 Control                     */
__sfr __at (0x9C) CPT1MD        ; /* Comparator 1 Mode                        */
__sfr __at (0x9D) CPT0MD        ; /* Comparator 0 Mode                        */
__sfr __at (0x9E) CPT1MX        ; /* Comparator 1 Mux                         */
__sfr __at (0x9F) CPT0MX        ; /* Comparator 0 Mux                         */
__sfr __at (0xA0) P2            ; /* Port 2 Latch                             */
__sfr __at (0xA1) SPI0CFG       ; /* SPI0 Configuration                       */
__sfr __at (0xA2) SPI0CKR       ; /* SPI0 Clock rate control                  */
__sfr __at (0xA3) SPI0DAT       ; /* SPI0 Data Buffer                         */
__sfr __at (0xA4) P0MDOUT       ; /* Port 0 Output Mode                       */
__sfr __at (0xA5) P1MDOUT       ; /* Port 1 Output Mode                       */
__sfr __at (0xA6) P2MDOUT       ; /* Port 2 Output Mode                       */
__sfr __at (0xA7) P3MDOUT       ; /* Port 3 Output Mode                       */
__sfr __at (0xA8) IE            ; /* Interrupt Enable                         */
__sfr __at (0xA9) CLKSEL        ; /* Clock Select                             */
__sfr __at (0xAA) EMI0CN        ; /* EMIF control                             */
__sfr __at (0xAA) _XPAGE        ; /* XDATA/PDATA PAGE                         */
__sfr __at (0xAC) SBCON1        ; /* UART1 Baud Rate Generator Control        */
__sfr __at (0xAE) P4MDOUT       ; /* Port 4 Mode                              */
__sfr __at (0xAF) PFE0CN        ; /* Prefetch Engine Control                  */
__sfr __at (0xB0) P3            ; /* Port 3 Latch                             */
__sfr __at (0xB1) OSCXCN        ; /* External Oscillator Control              */
__sfr __at (0xB2) OSCICN        ; /* Internal Oscillator Control              */
__sfr __at (0xB3) OSCICL        ; /* Internal Oscillator Calibration          */
__sfr __at (0xB4) SBRLL1        ; /* UART1 Baud Rate Generator Low            */
__sfr __at (0xB5) SBRLH1        ; /* UART1 Baud Rate Generator High           */
__sfr __at (0xB6) FLSCL         ; /* Flash Scale                              */
__sfr __at (0xB7) FLKEY         ; /* Flash Lock and Key                       */
__sfr __at (0xB8) IP            ; /* Interrupt Priority                       */
__sfr __at (0xB9) CLKMUL        ; /* Clock Multiplier                (page 0) */
__sfr __at (0xBA) AMX0N         ; /* AMUX0 Negative Channel Select            */
__sfr __at (0xBB) AMX0P         ; /* AMUX0 Positive Channel Select            */
__sfr __at (0xBC) ADC0CF        ; /* ADC0 Configuration              (page 0) */
__sfr __at (0xBD) ADC0L         ; /* ADC0 Low                                 */
__sfr __at (0xBE) ADC0H         ; /* ADC0 High                                */
__sfr __at (0xBF) SFRPAGE       ; /* SFR Page Select                          */
__sfr __at (0xB9) SMBTC         ; /* SMBus0/1 Timing Control         (page F) */
__sfr __at (0xC0) SMB0CN        ; /* SMBus0 Control                  (page 0) */
__sfr __at (0xC1) SMB0CF        ; /* SMBus0 Configuration            (page 0) */
__sfr __at (0xC2) SMB0DAT       ; /* SMBus0 Data                     (page 0) */
__sfr __at (0xC3) ADC0GTL       ; /* ADC0 Greater-Than Compare Low            */
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

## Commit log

2015-05-30 Add BOM info.
2015-06-04 Change LED blinking.
2016-02-18 Fix compile error generated by sdcc 3.3.1 #8894
    [main.c]
2016-02-24 Fix include file name for case sensitive environment
